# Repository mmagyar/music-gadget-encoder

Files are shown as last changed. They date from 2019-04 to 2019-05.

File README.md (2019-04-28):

# Music gadget base on STM32G070 MCU

# Modes of operation
 - Step sequencer
 - Midi controller
 
# Software
This project is built on a basic STM32Cube generated base, with using LL drivers.
TrueSTUDIO for STM32 is used for building and debugging.

# Hardware
The schematics and the pcb is designed with KiCad.
This is not a pcb that can be easily done at home, but most cheap chinease pcb manufaturers will be able to make them for you.
It uses 0805 SMD components, soldering this together is not for beginner.

# Picture of the prototype
In step sequencer mode:
in step sequencer mode

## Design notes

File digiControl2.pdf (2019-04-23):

## digiControl2 Project Configuration Report

# 1. Description

## 1.1. Project

Project Name | digiControl2
Board Name | custom
Generated with: | STM32CubeMX 5.0.0
Date | 04/14/2019

## 1.2. MCU

MCU Series | STM32G0
MCU Line | STM32G0x0 Value line
MCU name | STM32G070CBTx
MCU Package | LQFP48
MCU Pin number | 48

# 2. Pinout Configuration

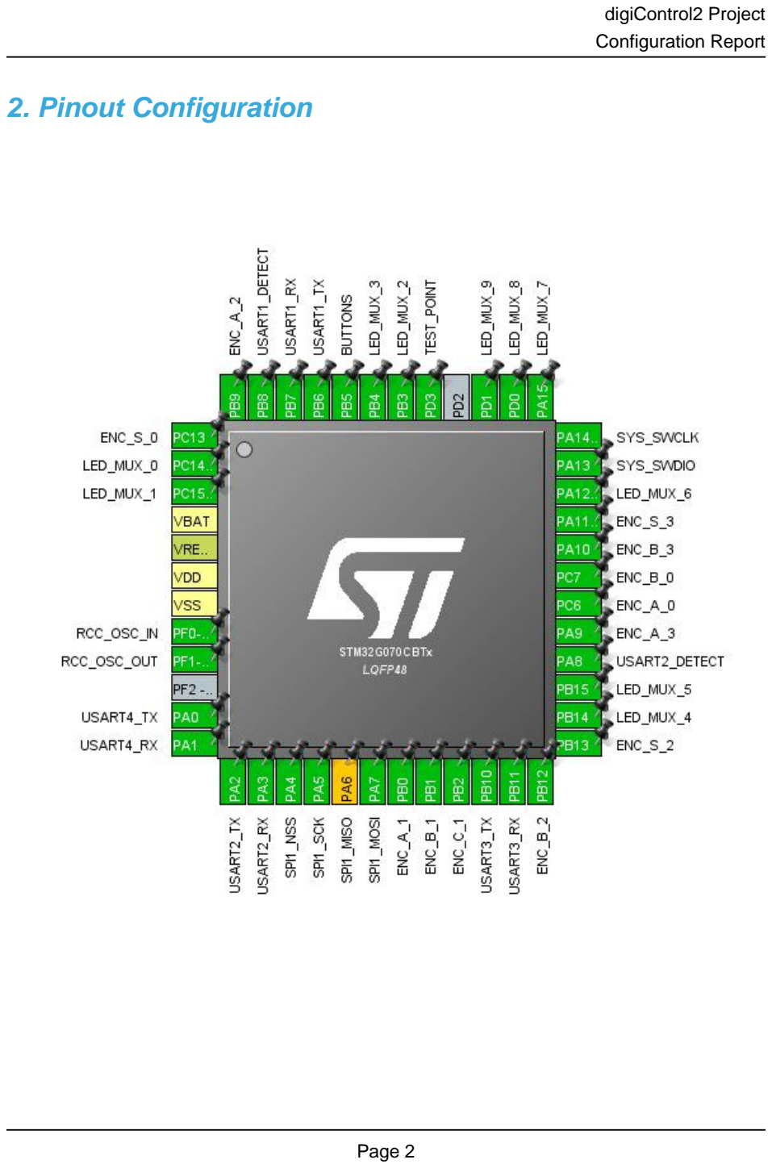
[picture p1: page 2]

# 3. Pins Configuration

Pin Number LQFP48 | Pin Name (function after reset) | Pin Type | Alternate Function(s) | Label
1 | PC13 * | I/O | GPIO_Input | ENC_S_0
2 | PC14-OSC32_IN (PC14) * | I/O | GPIO_Output | LED_MUX_0
3 | PC15-OSC32_OUT (PC15) * | I/O | GPIO_Output | LED_MUX_1
4 | VBAT | Power
5 | VREF+ | MonoIO
6 | VDD | Power
7 | VSS | Power
8 | PF0-OSC_IN (PF0) | I/O | RCC_OSC_IN
9 | PF1-OSC_OUT (PF1) | I/O | RCC_OSC_OUT
11 | PA0 | I/O | USART4_TX
12 | PA1 | I/O | USART4_RX
13 | PA2 | I/O | USART2_TX
14 | PA3 | I/O | USART2_RX
15 | PA4 | I/O | SPI1_NSS
16 | PA5 | I/O | SPI1_SCK
17 | PA6 ** | I/O | SPI1_MISO
18 | PA7 | I/O | SPI1_MOSI
19 | PB0 * | I/O | GPIO_Input | ENC_A_1
20 | PB1 * | I/O | GPIO_Input | ENC_B_1
21 | PB2 * | I/O | GPIO_Input | ENC_C_1
22 | PB10 | I/O | USART3_TX
23 | PB11 | I/O | USART3_RX
24 | PB12 * | I/O | GPIO_Input | ENC_B_2
25 | PB13 * | I/O | GPIO_Input | ENC_S_2
26 | PB14 * | I/O | GPIO_Output | LED_MUX_4
27 | PB15 * | I/O | GPIO_Output | LED_MUX_5
28 | PA8 * | I/O | GPIO_Input | USART2_DETECT
29 | PA9 * | I/O | GPIO_Input | ENC_A_3
30 | PC6 * | I/O | GPIO_Input | ENC_A_0
31 | PC7 * | I/O | GPIO_Input | ENC_B_0
32 | PA10 * | I/O | GPIO_Input | ENC_B_3
33 | PA11 [PA9] * | I/O | GPIO_Input | ENC_S_3
34 | PA12 [PA10] * | I/O | GPIO_Output | LED_MUX_6
35 | PA13 | I/O | SYS_SWDIO
36 | PA14-BOOT0 | I/O | SYS_SWCLK

Pin Number LQFP48 | Pin Name (function after reset) | Pin Type | Alternate Function(s) | Label
37 | PA15 * | I/O | GPIO_Output | LED_MUX_7
38 | PD0 * | I/O | GPIO_Output | LED_MUX_8
39 | PD1 * | I/O | GPIO_Output | LED_MUX_9
41 | PD3 * | I/O | GPIO_Output | TEST_POINT
42 | PB3 * | I/O | GPIO_Output | LED_MUX_2
43 | PB4 * | I/O | GPIO_Output | LED_MUX_3
44 | PB5 * | I/O | GPIO_Input | BUTTONS
45 | PB6 | I/O | USART1_TX
46 | PB7 | I/O | USART1_RX
47 | PB8 * | I/O | GPIO_Input | USART1_DETECT
48 | PB9 * | I/O | GPIO_Input | ENC_A_2

## * The pin is affected with an I/O function ** The pin is affected with a peripheral function but no peripheral mode is activated

# 4. Clock Tree Configuration

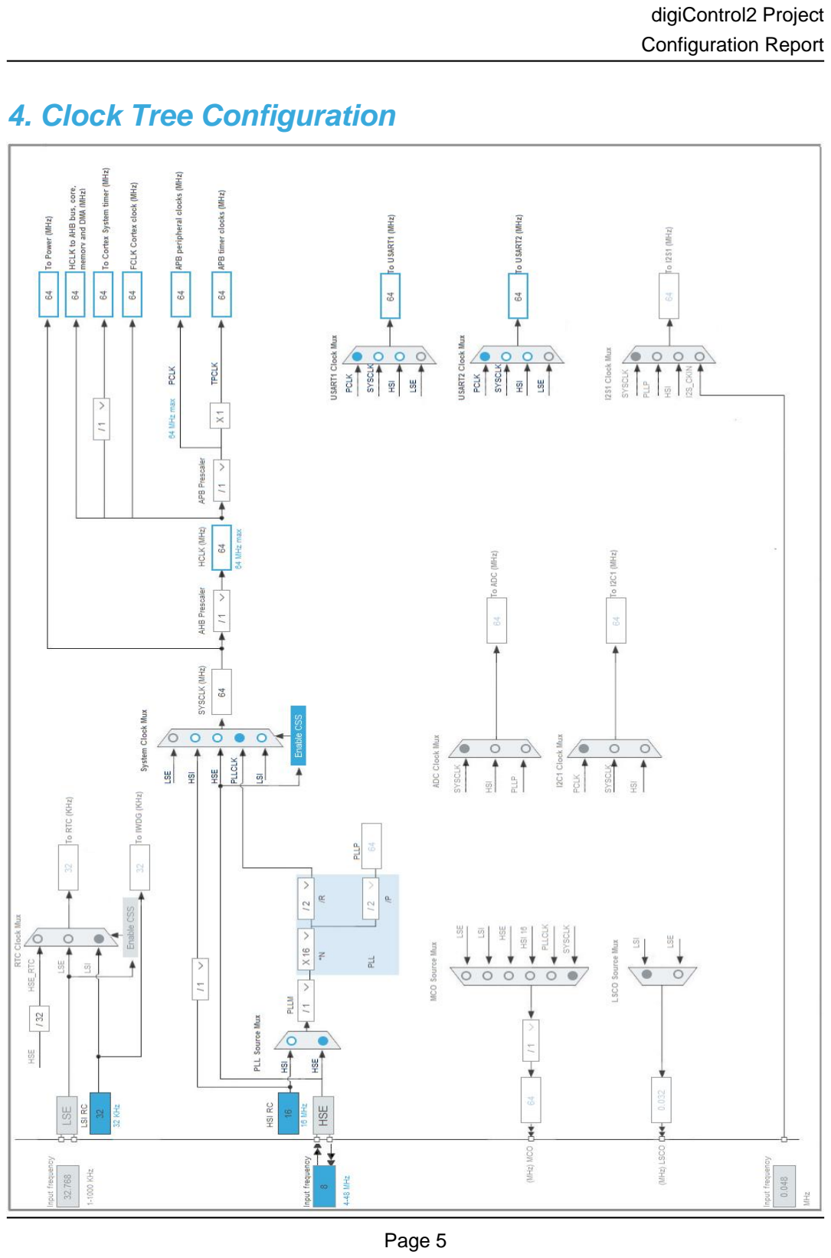
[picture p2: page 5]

# 5. Software Project

## 5.1. Project Settings

Name | Value
Project Name | digiControl2
Project Folder | C:\code\STM32_workspace_9.2\digiControl2\digiControl2
Toolchain / IDE | TrueSTUDIO
Firmware Package Name and Version | STM32Cube FW_G0 V1.0.0

## 5.2. Code Generation Settings

Name | Value
STM32Cube Firmware Library Package | Copy only the necessary library files
Generate peripheral initialization as a pair of '.c/.h' files | Yes
Backup previously generated files when re-generating | No
Delete previously generated files when not re-generated | Yes
Set all free pins as analog (to optimize the power consumption) | Yes

# 6. Power Consumption Calculator report

### 6.1. Microcontroller Selection

Series | STM32G0
Line | STM32G0x0 Value line
MCU | STM32G070CBTx
Datasheet | DS12766_Rev0

### 6.2. Parameter Selection

Temperature | 25
Vdd | null

# 7. IPs and Middleware Configuration

# 7.1. RCC

## High Speed Clock (HSE): Crystal/Ceramic Resonator 7.1.1. Parameter Settings:

### System Parameters:

VDD voltage (V) | 3.3
Instruction Cache | Enabled
Prefetch Buffer | Disabled
Data Cache | Enabled
Flash Latency(WS) | 2 WS (3 CPU cycle)

### RCC Parameters:

HSI Calibration Value | 64
HSE Startup Timout Value (ms) | 100
LSE Startup Timout Value (ms) | 5000

### Power Parameters:

Power Regulator Voltage Scale | Power Regulator Voltage Scale 1

### Peripherals Clock Configuration:

Generate the peripherals clock configuration | TRUE

# 7.2. SPI1

## Mode: Transmit Only Master Hardware NSS Signal: Hardware NSS Output Signal 7.2.1. Parameter Settings:

### Basic Parameters:

Frame Format | TI *
Data Size | 16 Bits *

### Clock Parameters:

Prescaler (for Baud Rate) | 4 *
Baud Rate | 16.0 MBits/s *

### Advanced Parameters:

CRC Calculation | Disabled
NSS Signal Type | Output Hardware

# 7.3. SYS

## mode: Debug Timebase Source: SysTick

# 7.4. USART1

## Mode: Asynchronous 7.4.1. Parameter Settings:

### Basic Parameters:

Baud Rate | 115200
Word Length | 9 Bits (including Parity) *
Parity | Even *
Stop Bits | 1

### Advanced Parameters:

Data Direction | Receive and Transmit
Over Sampling | 16 Samples
Single Sample | Disable
ClockPrescaler | clock /1
Fifo Mode | Disable
Txfifo Threshold | 1 eighth full configuration
Rxfifo Threshold | 1 eighth full configuration

### Advanced Features:

Auto Baudrate | Disable
TX Pin Active Level Inversion | Disable
RX Pin Active Level Inversion | Disable
Data Inversion | Disable
TX and RX Pins Swapping | Disable
Overrun | Enable
DMA on RX Error | Enable
MSB First | Disable

# 7.5. USART2

## Mode: Asynchronous 7.5.1. Parameter Settings:

### Basic Parameters:

Baud Rate | 115200
Word Length | 9 Bits (including Parity) *
Parity | Even *
Stop Bits | 1

### Advanced Parameters:

Data Direction | Receive and Transmit
Over Sampling | 16 Samples
Single Sample | Disable
ClockPrescaler | clock /1
Fifo Mode | Disable
Txfifo Threshold | 1 eighth full configuration
Rxfifo Threshold | 1 eighth full configuration

### Advanced Features:

Auto Baudrate | Disable
TX Pin Active Level Inversion | Disable
RX Pin Active Level Inversion | Disable
Data Inversion | Disable
TX and RX Pins Swapping | Disable
Overrun | Enable
DMA on RX Error | Enable
MSB First | Disable

# 7.6. USART3

## Mode: Asynchronous 7.6.1. Parameter Settings:

### Basic Parameters:

Baud Rate | 115200
Word Length | 9 Bits (including Parity) *
Parity | Even *
Stop Bits | 1

### Advanced Parameters:

Data Direction | Receive and Transmit
Over Sampling | 16 Samples
Single Sample | Disable
ClockPrescaler | clock /1
Fifo Mode | Disable
Txfifo Threshold | 1 eighth full configuration
Rxfifo Threshold | 1 eighth full configuration

### Advanced Features:

TX Pin Active Level Inversion | Disable
RX Pin Active Level Inversion | Disable
Data Inversion | Disable
TX and RX Pins Swapping | Disable
Overrun | Enable
DMA on RX Error | Enable
MSB First | Disable

# 7.7. USART4

## Mode: Asynchronous 7.7.1. Parameter Settings:

### Basic Parameters:

Baud Rate | 115200
Word Length | 9 Bits (including Parity) *
Parity | Even *
Stop Bits | 1

### Advanced Parameters:

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

### Advanced Features:

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

### * User modified value

# 8. System Configuration

# 8.1. GPIO configuration

IP | Pin | Signal | GPIO mode | GPIO pull/up pull down

## Max Speed

## User Label

RCC PF0-OSC_IN
(PF0)
RCC_OSC_IN | n/a | n/a | n/a

PF1-
OSC_OUT
(PF1)
RCC_OSC_OUT | n/a | n/a | n/a
SPI1 | PA4 | SPI1_NSS | Alternate Function Push Pull | No pull-up and no pull-down | High *
| PA5 | SPI1_SCK | Alternate Function Push Pull | No pull-up and no pull-down | High *
| PA7 | SPI1_MOSI | Alternate Function Push Pull | No pull-up and no pull-down | High *
SYS | PA13 | SYS_SWDIO | n/a | n/a | n/a
| PA14- BOOT0 | SYS_SWCLK | n/a | n/a | n/a
USART1 | PB6 | USART1_TX | Alternate Function Push Pull | Pull-up | Low
| PB7 | USART1_RX | Alternate Function Push Pull | Pull-up | Low
USART2 | PA2 | USART2_TX | Alternate Function Push Pull | Pull-up | Low
| PA3 | USART2_RX | Alternate Function Push Pull | Pull-up | Low
USART3 | PB10 | USART3_TX | Alternate Function Push Pull | Pull-up | Low
| PB11 | USART3_RX | Alternate Function Push Pull | Pull-up | Low
USART4 | PA0 | USART4_TX | Alternate Function Push Pull | Pull-up | Low
| PA1 | USART4_RX | Alternate Function Push Pull | Pull-up | Low
Single Mapped Signals | PA6 | SPI1_MISO | Alternate Function Push Pull | No pull-up and no pull-down | Low
GPIO | PC13 | GPIO_Input | Input mode | No pull-up and no pull-down | n/a | ENC_S_0
| PC14- OSC32_IN (PC14) | GPIO_Output | Output Push Pull | No pull-up and no pull-down | Low | LED_MUX_0

PC15-
OSC32_OU
T (PC15)
GPIO_Output | Output Push Pull | No pull-up and no pull-down | Low | LED_MUX_1
PB0 | GPIO_Input | Input mode | No pull-up and no pull-down | n/a | ENC_A_1
PB1 | GPIO_Input | Input mode | No pull-up and no pull-down | n/a | ENC_B_1
PB2 | GPIO_Input | Input mode | No pull-up and no pull-down | n/a | ENC_C_1
PB12 | GPIO_Input | Input mode | No pull-up and no pull-down | n/a | ENC_B_2
PB13 | GPIO_Input | Input mode | No pull-up and no pull-down | n/a | ENC_S_2
PB14 | GPIO_Output | Output Push Pull | No pull-up and no pull-down | Low | LED_MUX_4
PB15 | GPIO_Output | Output Push Pull | No pull-up and no pull-down | Low | LED_MUX_5
PA8 | GPIO_Input | Input mode | No pull-up and no pull-down | n/a | USART2_DETECT

IP | Pin | Signal | GPIO mode | GPIO pull/up pull down | Max Speed | User Label
| PA9 | GPIO_Input | Input mode | No pull-up and no pull-down | n/a | ENC_A_3
| PC6 | GPIO_Input | Input mode | No pull-up and no pull-down | n/a | ENC_A_0
| PC7 | GPIO_Input | Input mode | No pull-up and no pull-down | n/a | ENC_B_0
| PA10 | GPIO_Input | Input mode | No pull-up and no pull-down | n/a | ENC_B_3
| PA11 [PA9] | GPIO_Input | Input mode | No pull-up and no pull-down | n/a | ENC_S_3
| PA12 [PA10] | GPIO_Output | Output Push Pull | No pull-up and no pull-down | Low | LED_MUX_6
| PA15 | GPIO_Output | Output Push Pull | No pull-up and no pull-down | Low | LED_MUX_7
| PD0 | GPIO_Output | Output Push Pull | No pull-up and no pull-down | Low | LED_MUX_8
| PD1 | GPIO_Output | Output Push Pull | No pull-up and no pull-down | Low | LED_MUX_9
| PD3 | GPIO_Output | Output Push Pull | No pull-up and no pull-down | Low | TEST_POINT
| PB3 | GPIO_Output | Output Push Pull | No pull-up and no pull-down | Low | LED_MUX_2
| PB4 | GPIO_Output | Output Push Pull | No pull-up and no pull-down | Low | LED_MUX_3
| PB5 | GPIO_Input | Input mode | No pull-up and no pull-down | n/a | BUTTONS
| PB8 | GPIO_Input | Input mode | No pull-up and no pull-down | n/a | USART1_DETECT
| PB9 | GPIO_Input | Input mode | No pull-up and no pull-down | n/a | ENC_A_2

# 8.2. DMA configuration

DMA request | Stream | Direction | Priority
SPI1_TX | DMA1_Channel1 | Memory To Peripheral | Low

## SPI1_TX: DMA1_Channel1 DMA request Settings:

Mode: | Normal
Peripheral Increment: | Disable
Memory Increment: | Disable
Peripheral Data Width: | Half Word
Memory Data Width: | Half Word

# 8.3. NVIC configuration

Interrupt Table | Enable | Preenmption Priority | SubPriority
Non maskable interrupt | true | 0 | 0
Hard fault interrupt | true | 0 | 0
System service call via SWI instruction | true | 0 | 0
Pendable request for system service | true | 0 | 0
System tick timer | true | 0 | 0
RCC global interrupt | true | 0 | 0
DMA1 channel 1 interrupt | true | 0 | 0
DMA1 channel 4, channel 5, channel 6, channel 7 and DMAMUX1 interrupts | true | 0 | 0
SPI1 global interrupt | true | 0 | 0
Flash global interrupt | unused
USART1 global interrupt / USART1 wake-up interrupt through EXTI line 25 | unused
USART2 global interrupt / USART2 wake-up interrupt through EXTI line 26 | unused
USART3 and USART4 interrupts | unused

### * User modified value

# 9. Software Pack Report

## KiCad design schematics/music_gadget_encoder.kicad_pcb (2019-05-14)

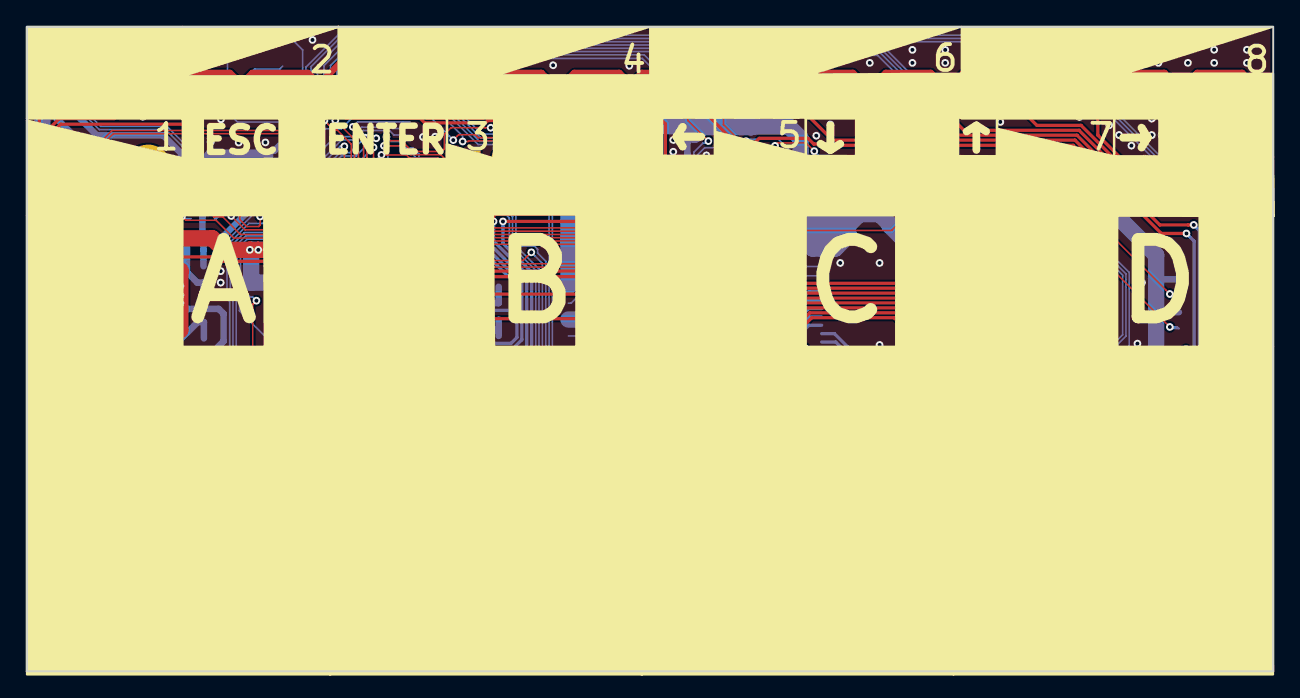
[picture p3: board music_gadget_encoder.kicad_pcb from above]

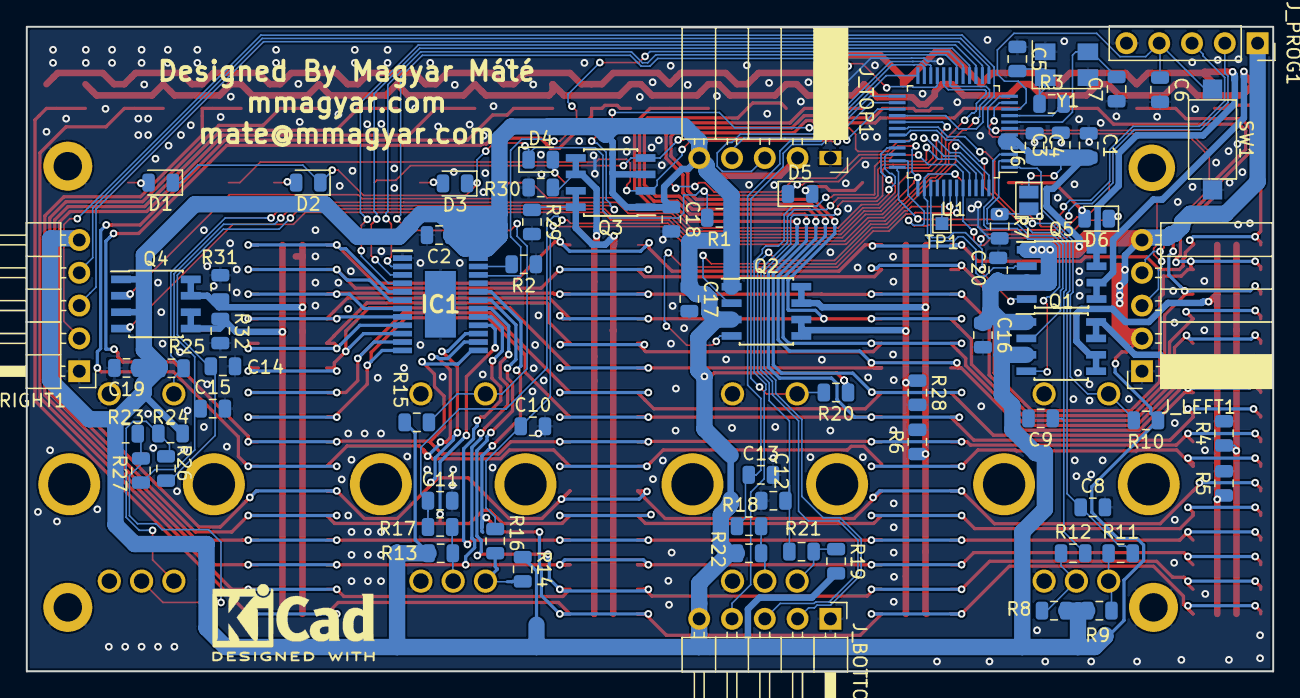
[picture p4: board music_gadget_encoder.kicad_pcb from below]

Board: 2 copper layers, 96.5 x 49.9 mm, 248 parts (74 on the bottom side), 87 nets.

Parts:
C1: 4.7u; C_0805_2012Metric
C2, C3, C4, C16, C17, C18, C19, C20: 100n; C_0805_2012Metric
C5, C7: 18pf; C_0805_2012Metric
C6: 100nf; C_0805_2012Metric
C8, C9, C10, C11, C12, C13, C14, C15: 10n; C_0805_2012Metric
D1, D2, D3, D4, D5, D6: DIODE; D_0805_2012Metric
D9, D10, D11, D12, D13, D14, D15, D16, D17, D18, D19, D20, D21, D22, D23, D24, D25, D26, D27, D28, D29, D30, D31, D32, D33, D34, D35, D36, D37, D38, D39, D40, D41, D42, D43, D44, D45, D46, D47, D48, D49, D50, D51, D52, D53, D54, D55, D56, D57, D58, D59, D60, D61, D62, D63, D64, D65, D66, D67, D68, D69, D70, D71, D72, D73, D74, D75, D76, D77, D78, D79, D80, D81, D82, D83, D84, D85, D86, D87, D88, D89, D90, D91, D92, D93, D94, D95, D96, D97, D98, D99, D100, D101, D102, D103, D104, D105, D106, D107, D108, D109, D110, D111, D112, D113, D114, D115, D116, D117, D118, D119, D120, D121, D122, D123, D124, D125, D126, D127, D128, D129, D130, D131, D132, D133, D134, D135, D136, D137, D138, D139, D140, D141, D142, D143, D144, D145, D146, D147, D148, D149, D150, D151, D152, D153, D154, D155, D156, D157, D158, D159, D160, D161, D162, D163, D164, D165, D166, D167, D168: LED; LED_0805_2012Metric_NO_SILKSCREEN
H1, H2, H3, H4: MountingHole_Pad; MountingHole_2.2mm_M2_DIN965_Pad
IC1: TLC5926IPWPR; SOP65P640X120-25N
J6: Conn_01x02_Male; SolderJumper-2_P1.3mm_Open_Pad1.0x1.5mm
J_BOTTOM1: Conn_01x05; PinHeader_1x05_P2.54mm_Horizontal
J_LEFT1: Conn_01x05; PinSocket_1x05_P2.54mm_Horizontal
J_PROG1: Conn_01x05; PinSocket_1x05_P2.54mm_Vertical
J_RIGHT1: Conn_01x05; PinHeader_1x05_P2.54mm_Horizontal
J_TOP1: Conn_01x05; PinSocket_1x05_P2.54mm_Horizontal
Q1, Q2, Q3, Q4, Q5: DMG9933USD-13; SOIC-8_3.9x4.9mm_P1.27mm
R1, R7: 10k; R_0805_2012Metric
R2: R; R_0805_2012Metric
R3: 390; R_0805_2012Metric
R4, R5, R6, R28, R29, R30, R31, R32: 1k; R_0805_2012Metric
R8, R9, R10, R11, R12, R13, R14, R15, R16, R17, R18, R19, R20, R21, R22, R23, R24, R25, R26, R27: 10K; R_0805_2012Metric
SW1, SW2, SW3, SW4, SW5, SW6, SW7: SW_Push; SW_SPST_CK_RS282G05A3
TP1: TestPoint; TestPoint_Pad_1.0x1.0mm
U1: STM32G070CBTx; LQFP-48_7x7mm_P0.5mm
U2, U3, U4, U5: PEC12R-4225F-S0024; ENCODER_PEC12R-4XXXF-SXXXX_1
Y1: Crystal_GND24; Crystal_SMD_5032-4Pin_5.0x3.2mm

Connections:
/BUTTONS: D1.1, D2.1, D3.1, D4.1, D5.1, D6.1, R1.2, U1.44
/ENC_A_0: C8.1, R11.2, U1.30
/ENC_A_1: C10.1, R16.2, U1.19
/ENC_A_2: C12.1, R21.2, U1.48
/ENC_A_3: C14.1, R26.2, U1.29
/ENC_B_0: C9.1, R12.2, U1.31
/ENC_B_1: C11.1, R17.2, U1.20
/ENC_B_2: C13.1, R22.2, U1.24
/ENC_B_3: C15.1, R27.2, U1.32
/ENC_S_0: R10.2, U1.1, U2.4
/ENC_S_1: R15.2, U1.21, U3.4
/ENC_S_2: R20.2, U1.25, U4.4
/ENC_S_3: R25.2, U1.33, U5.4
/LED_0: D9.1, D10.1, D41.1, D42.1, D73.1, D74.1, D105.1, D106.1, D137.1, D138.1, IC1.5
/LED_1: D11.1, D12.1, D43.1, D44.1, D75.1, D76.1, D107.1, D108.1, D139.1, D140.1, IC1.6
/LED_2: D13.1, D14.1, D45.1, D46.1, D77.1, D78.1, D109.1, D110.1, D141.1, D142.1, IC1.7
/LED_3: D15.1, D16.1, D47.1, D48.1, D79.1, D80.1, D111.1, D112.1, D143.1, D144.1, IC1.8
/LED_4: D17.1, D18.1, D49.1, D50.1, D81.1, D82.1, D113.1, D114.1, D145.1, D146.1, IC1.9
/LED_5: D19.1, D20.1, D51.1, D52.1, D83.1, D84.1, D115.1, D116.1, D147.1, D148.1, IC1.10
/LED_6: D21.1, D22.1, D53.1, D54.1, D85.1, D86.1, D117.1, D118.1, D149.1, D150.1, IC1.11
/LED_7: D23.1, D24.1, D55.1, D56.1, D87.1, D88.1, D119.1, D120.1, D151.1, D152.1, IC1.12
/LED_8: D25.1, D26.1, D57.1, D58.1, D89.1, D90.1, D121.1, D122.1, D153.1, D154.1, IC1.13
/LED_9: D27.1, D28.1, D59.1, D60.1, D91.1, D92.1, D123.1, D124.1, D155.1, D156.1, IC1.14
/LED_10: D29.1, D30.1, D61.1, D62.1, D93.1, D94.1, D125.1, D126.1, D157.1, D158.1, IC1.15
/LED_11: D31.1, D32.1, D63.1, D64.1, D95.1, D96.1, D127.1, D128.1, D159.1, D160.1, IC1.16
/LED_12: D33.1, D34.1, D65.1, D66.1, D97.1, D98.1, D129.1, D130.1, D161.1, D162.1, IC1.17
/LED_13: D35.1, D36.1, D67.1, D68.1, D99.1, D100.1, D131.1, D132.1, D163.1, D164.1, IC1.18
/LED_14: D37.1, D38.1, D69.1, D70.1, D101.1, D102.1, D133.1, D134.1, D165.1, D166.1, IC1.19
/LED_15: D39.1, D40.1, D71.1, D72.1, D103.1, D104.1, D135.1, D136.1, D167.1, D168.1, IC1.20
/LED_MUX_0: Q1.2, U1.2
/LED_MUX_1: Q1.4, U1.3
/LED_MUX_2: Q2.2, U1.42
/LED_MUX_3: Q2.4, U1.43
/LED_MUX_4: Q3.2, SW2.1, U1.26
/LED_MUX_5: Q3.4, SW3.1, U1.27
/LED_MUX_6: Q4.2, SW4.1, U1.34
/LED_MUX_7: Q4.4, SW5.1, U1.37
/LED_MUX_8: Q5.2, SW6.1, U1.38
/LED_MUX_9: Q5.4, SW7.1, U1.39
/MISO: IC1.22, U1.17
/MOSI: IC1.2, U1.18
/NSS: IC1.4, U1.15
/RESET: C6.1, J_PROG1.4, SW1.1, U1.10
/SCLK: IC1.3, U1.16
/SWCLK: J6.1, J_PROG1.3, R7.1, U1.36
/SWDIO: J_PROG1.2, U1.35
/USART1_DETECT: J_BOTTOM1.2, U1.47
/USART1_RX: J_BOTTOM1.3, U1.46
/USART1_TX: J_BOTTOM1.4, U1.45
/USART2_DETECT: J_RIGHT1.2, U1.28
/USART2_RX: J_RIGHT1.3, U1.14
/USART2_TX: J_RIGHT1.4, U1.13
/USART3_RX: J_TOP1.4, U1.23
/USART3_TX: J_TOP1.3, U1.22
/USART4_RX: J_LEFT1.4, U1.12
/USART4_TX: J_LEFT1.3, U1.11
GND: C1.1, C2.2, C3.2, C4.1, C5.1, C6.2, C7.1, C8.2, C9.2, C10.2, C11.2, C12.2, C13.2, C14.2, C15.2, C16.2, C17.2, C18.2, C19.2, C20.2, H1.1, H2.1, H3.1, H4.1, IC1.1, IC1.21, IC1.25, J_BOTTOM1.1, J_LEFT1.1, J_PROG1.5, J_RIGHT1.1, J_TOP1.1, R2.1, R4.2, R5.2, R6.2, R7.2, R28.2, R29.2, R30.2, R31.2, R32.2, SW1.2, U1.7, U2.2, U2.5, U3.2, U3.5, U4.2, U4.5, U5.2, U5.5, Y1.2, Y1.4
unnamed: C5.2, R3.1, Y1.1
unnamed: C7.2, U1.8, Y1.3
unnamed: D1.2, SW2.2
unnamed: D2.2, SW3.2
unnamed: D3.2, SW4.2
unnamed: D4.2, SW5.2
unnamed: D5.2, SW6.2
unnamed: D6.2, SW7.2
unnamed: D10.2, D12.2, D14.2, D16.2, D18.2, D20.2, D22.2, D24.2, D26.2, D28.2, D30.2, D32.2, D34.2, D36.2, D38.2, D40.2, Q1.7, Q1.8, R4.1
unnamed: D9.2, D11.2, D13.2, D15.2, D17.2, D19.2, D21.2, D23.2, D25.2, D27.2, D29.2, D31.2, D33.2, D35.2, D37.2, D39.2, Q1.5, Q1.6, R5.1
unnamed: D41.2, D43.2, D45.2, D47.2, D49.2, D51.2, D53.2, D55.2, D57.2, D59.2, D61.2, D63.2, D65.2, D67.2, D69.2, D71.2, Q2.5, Q2.6, R28.1
unnamed: D42.2, D44.2, D46.2, D48.2, D50.2, D52.2, D54.2, D56.2, D58.2, D60.2, D62.2, D64.2, D66.2, D68.2, D70.2, D72.2, Q2.7, Q2.8, R6.1
unnamed: D74.2, D76.2, D78.2, D80.2, D82.2, D84.2, D86.2, D88.2, D90.2, D92.2, D94.2, D96.2, D98.2, D100.2, D102.2, D104.2, Q3.7, Q3.8, R29.1
unnamed: D73.2, D75.2, D77.2, D79.2, D81.2, D83.2, D85.2, D87.2, D89.2, D91.2, D93.2, D95.2, D97.2, D99.2, D101.2, D103.2, Q3.5, Q3.6, R30.1
unnamed: D105.2, D107.2, D109.2, D111.2, D113.2, D115.2, D117.2, D119.2, D121.2, D123.2, D125.2, D127.2, D129.2, D131.2, D133.2, D135.2, Q4.5, Q4.6, R32.1
unnamed: D106.2, D108.2, D110.2, D112.2, D114.2, D116.2, D118.2, D120.2, D122.2, D124.2, D126.2, D128.2, D130.2, D132.2, D134.2, D136.2, Q4.7, Q4.8, R31.1
unnamed: D137.2, D139.2, D141.2, D143.2, D145.2, D147.2, D149.2, D151.2, D153.2, D155.2, D157.2, D159.2, D161.2, D163.2, D165.2, D167.2, Q5.5, Q5.6
unnamed: D138.2, D140.2, D142.2, D144.2, D146.2, D148.2, D150.2, D152.2, D154.2, D156.2, D158.2, D160.2, D162.2, D164.2, D166.2, D168.2, Q5.7, Q5.8
unnamed: IC1.23, R2.2
unnamed: R3.2, U1.9
unnamed: R9.2, R11.1, U2.1
unnamed: R8.2, R12.1, U2.3
unnamed: R13.2, R17.1, U3.3
unnamed: R14.2, R16.1, U3.1
unnamed: R18.2, R22.1, U4.3
unnamed: R19.2, R21.1, U4.1
unnamed: R23.2, R27.1, U5.3
unnamed: R24.2, R26.1, U5.1
unnamed: TP1.1, U1.41
VCC: C1.2, C2.1, C3.1, C4.2, C16.1, C17.1, C18.1, C19.1, C20.1, IC1.24, J6.2, J_BOTTOM1.5, J_LEFT1.2, J_LEFT1.5, J_PROG1.1, J_RIGHT1.5, J_TOP1.2, J_TOP1.5, Q1.1, Q1.3, Q2.1, Q2.3, Q3.1, Q3.3, Q4.1, Q4.3, Q5.1, Q5.3, R1.1, R8.1, R9.1, R10.1, R13.1, R14.1, R15.1, R18.1, R19.1, R20.1, R23.1, R24.1, R25.1, U1.4, U1.5, U1.6

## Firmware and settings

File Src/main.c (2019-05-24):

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

/* Includes ------------------------------------------------------------------*/
#include "main.h"
#include "crc.h"
#include "spi.h"
#include "tim.h"
#include "usart.h"
#include "gpio.h"

/* USER CODE BEGIN Includes */
#include "mainthread.h"
#include "lib/printf.h"
/* USER CODE END Includes */


void SystemClock_Config(void);
static void MX_NVIC_Init(void);
/**
 * @brief  The application entry point.
 * @retval int
 */
int main(void)
{
    /* MCU Configuration--------------------------------------------------------*/

    /* Reset of all peripherals, Initializes the Flash interface and the Systick. */

    LL_APB2_GRP1_EnableClock(LL_APB2_GRP1_PERIPH_SYSCFG);
    LL_APB1_GRP1_EnableClock(LL_APB1_GRP1_PERIPH_PWR);

    /* System interrupt init*/

    /* Peripheral interrupt init*/

    /* Configure the system clock */
    SystemClock_Config();

    /* Initialize all configured peripherals */
    MX_GPIO_Init();
    MX_SPI1_Init();
    MX_USART1_UART_Init();
    MX_USART2_UART_Init();
    MX_USART3_UART_Init();
    MX_USART4_UART_Init();
    MX_TIM3_Init();
    MX_TIM6_Init();
    MX_TIM7_Init();
    MX_TIM14_Init();
    MX_CRC_Init();

    /* Initialize interrupts */
    MX_NVIC_Init();
    /* Infinite loop */
    /* USER CODE BEGIN WHILE */

//    /* Start channel 3 in Output compare mode */
//    if (HAL_TIM_OC_Start_IT(&htim3, TIM_CHANNEL_1) != HAL_OK) {
//        /* Starting Error */
//        Error_Handler();
//    }
    LL_TIM_EnableCounter(TIM6);
    LL_TIM_EnableIT_UPDATE(TIM6);

    LL_TIM_EnableCounter(TIM7);
    LL_TIM_EnableIT_UPDATE(TIM7);

    LL_TIM_EnableCounter(TIM3);
    LL_TIM_EnableIT_UPDATE(TIM3);

    LL_TIM_EnableCounter(TIM14);
    LL_TIM_EnableIT_UPDATE(TIM14);

    LL_SPI_Enable(SPI1);
    LL_SPI_EnableIT_RXNE(SPI1);


    while ((!(LL_USART_IsActiveFlag_TEACK(USART4))) || (!(LL_USART_IsActiveFlag_REACK(USART4))));
    LL_USART_EnableIT_RXNE(USART4);
    LL_USART_EnableIT_ERROR(USART4);

    while ((!(LL_USART_IsActiveFlag_TEACK(USART3))) || (!(LL_USART_IsActiveFlag_REACK(USART3))));
    LL_USART_EnableIT_RXNE(USART3);
    LL_USART_EnableIT_ERROR(USART3);

    while ((!(LL_USART_IsActiveFlag_TEACK(USART2))) || (!(LL_USART_IsActiveFlag_REACK(USART2))));
    LL_USART_EnableIT_RXNE(USART2);
    LL_USART_EnableIT_ERROR(USART2);

    while ((!(LL_USART_IsActiveFlag_TEACK(USART1))) || (!(LL_USART_IsActiveFlag_REACK(USART1))));
    LL_USART_EnableIT_RXNE(USART1);
    LL_USART_EnableIT_ERROR(USART1);
//    LL_USART_TransmitData8(USART4, 'x');


    main_thread();

    /* USER CODE END WHILE */

}

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


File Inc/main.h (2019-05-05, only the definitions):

#define ENC_S_0_Pin LL_GPIO_PIN_13
#define ENC_S_0_GPIO_Port GPIOC
#define LED_MUX_0_Pin LL_GPIO_PIN_14
#define LED_MUX_0_GPIO_Port GPIOC
#define LED_MUX_1_Pin LL_GPIO_PIN_15
#define LED_MUX_1_GPIO_Port GPIOC
#define ENC_A_2_Pin LL_GPIO_PIN_0
#define ENC_A_2_GPIO_Port GPIOB
#define ENC_B_2_Pin LL_GPIO_PIN_1
#define ENC_B_2_GPIO_Port GPIOB
#define ENC_S_2_Pin LL_GPIO_PIN_2
#define ENC_S_2_GPIO_Port GPIOB
#define ENC_B_1_Pin LL_GPIO_PIN_12
#define ENC_B_1_GPIO_Port GPIOB
#define ENC_S_1_Pin LL_GPIO_PIN_13
#define ENC_S_1_GPIO_Port GPIOB
#define LED_MUX_4_Pin LL_GPIO_PIN_14
#define LED_MUX_4_GPIO_Port GPIOB
#define LED_MUX_5_Pin LL_GPIO_PIN_15
#define LED_MUX_5_GPIO_Port GPIOB
#define USART2_DETECT_Pin LL_GPIO_PIN_8
#define USART2_DETECT_GPIO_Port GPIOA
#define ENC_A_3_Pin LL_GPIO_PIN_9
#define ENC_A_3_GPIO_Port GPIOA
#define ENC_A_0_Pin LL_GPIO_PIN_6
#define ENC_A_0_GPIO_Port GPIOC
#define ENC_B_0_Pin LL_GPIO_PIN_7
#define ENC_B_0_GPIO_Port GPIOC
#define ENC_B_3_Pin LL_GPIO_PIN_10
#define ENC_B_3_GPIO_Port GPIOA
#define ENC_S_3_Pin LL_GPIO_PIN_11
#define ENC_S_3_GPIO_Port GPIOA
#define LED_MUX_6_Pin LL_GPIO_PIN_12
#define LED_MUX_6_GPIO_Port GPIOA
#define LED_MUX_7_Pin LL_GPIO_PIN_15
#define LED_MUX_7_GPIO_Port GPIOA
#define LED_MUX_8_Pin LL_GPIO_PIN_0
#define LED_MUX_8_GPIO_Port GPIOD
#define LED_MUX_9_Pin LL_GPIO_PIN_1
#define LED_MUX_9_GPIO_Port GPIOD
#define TEST_POINT_Pin LL_GPIO_PIN_3
#define TEST_POINT_GPIO_Port GPIOD
#define LED_MUX_2_Pin LL_GPIO_PIN_3
#define LED_MUX_2_GPIO_Port GPIOB
#define LED_MUX_3_Pin LL_GPIO_PIN_4
#define LED_MUX_3_GPIO_Port GPIOB
#define BUTTONS_Pin LL_GPIO_PIN_5
#define BUTTONS_GPIO_Port GPIOB
#define USART1_DETECT_Pin LL_GPIO_PIN_8
#define USART1_DETECT_GPIO_Port GPIOB
#define ENC_A_1_Pin LL_GPIO_PIN_9
#define ENC_A_1_GPIO_Port GPIOB
#define NVIC_PRIORITYGROUP_0         ((uint32_t)0x00000007) /*!< 0 bit  for pre-emption priority,
#define NVIC_PRIORITYGROUP_1         ((uint32_t)0x00000006) /*!< 1 bit  for pre-emption priority,
#define NVIC_PRIORITYGROUP_2         ((uint32_t)0x00000005) /*!< 2 bits for pre-emption priority,
#define NVIC_PRIORITYGROUP_3         ((uint32_t)0x00000004) /*!< 3 bits for pre-emption priority,
#define NVIC_PRIORITYGROUP_4         ((uint32_t)0x00000003) /*!< 4 bits for pre-emption priority,

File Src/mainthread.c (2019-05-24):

#include "mainthread.h"
#include "stm32g070xx.h"
#include "tim.h"
#include "util/error_log_code_text.h"
#include  <sys/unistd.h> // STDOUT_FILENO, STDERR_FILENO
#include "lib/printf.h"
#include "seq/seq.h"
#include "seq/control.h"
#include "system/inputs.h"
#include "system/led_update.h"
#include "system/mux.h"
#include "util/midi/midi.h"
#include "util/dataframe.h"
#include "system/intercom.h"
#include "system/uart.h"

Task tasks[max_task_count] = { 0 };
u32 ms_counter = 0;
u32 ms_last = 0;
const u8 TASK_INDEX_LED_UPDATE = 0;
const u8 TASK_INDEX_SEQ_UPDATE = 1;
const u8 TASK_INDEX_CONTROL_UPDATE = 2;
const u8 TASK_INDEX_COMM = 3;
const u8 TASK_ERROR_PRINT = 4;

u32 received_frames_count = 0;

void calculate_task_time(Task * task);

Icom_send icom_buffer[4] = { 0 };
Frame_Receive_buffer frame_buffer[4] = { 0 };

volatile int azz = 0;
void test_receive_control_change(Mcu_uid * origin, Control_change ch) {
    azz++;
 //   icom_send_control_change(&ch);
}
void test_receive_button_press(Mcu_uid * origin, Button_press bp) {
    azz++;
}
void test_receive_led_update(Mcu_uid * origin, Led_update lu) {
    azz++;
}

void test_receive_broadcast_response(Mcu_uid * origin, Broadcast_response br) {
    azz++;
}
void read_uart_rx_buffer() {
    Circular_buffer * cb[4] = {
            &uart_1_rx_buffer,
            &uart_2_rx_buffer,
            &uart_3_rx_buffer,
            &uart_4_rx_buffer };

    loop(x, 4)
    {
        Buffer_read_result brr = { 0 };

        get_from_buffer(cb[x], &brr);

        if (brr.readSuccess) {
            bool frame_end = receive_byte(brr.data, &frame_buffer[x]);

            if (frame_end) {
                received_frames_count++;
                icom_read_message(frame_buffer[x].buffer, frame_buffer[x].message_size,
                        &icom_buffer[x], x + 1);
            }
        }
    }

}

void error_print() {
    if (error_count) {
        printf("\r\nTotal number of errors occured: %d\r\n", error_count);
        loop(ec, ERROR_LOG_SIZE)
        {
            Error * e = &error_log[ec];
            if (e->error_code) {
                printf("ERR 0x%02X - %c (%d) : %s\r\n", e->error_code, e->identifier, e->identifier,
                        error_code_text[(u8) e->error_code]);

                e->error_code = 0;
                e->identifier = 0;
            }

        }
        error_count = 0;
    }
}

volatile int abcd = 0;
void test() {
    return;
    loop(x,8)
    {
        Control_change ch = { x, x * 2 };
        icom_send_control_change(&ch);
        volatile int i = 0;
        while (i < 100) {
            i++;
        }

    }

    //  Control_change ch = { 1, abcd++ };
    //  icom_send_control_change(&ch);
}
void crc_feed_stm32(Crc_state state, u8 byte) {
    LL_CRC_FeedData8(CRC, byte);
}

Crc_state crc_init_stm32() {
    LL_CRC_ResetCRCCalculationUnit(CRC);
    return 0;
}

u32 crc_get_stm32(Crc_state state) {
    u32 data = LL_CRC_ReadData32(CRC);
    LL_CRC_ResetCRCCalculationUnit(CRC);
    /* We need to invert it to get a standard CRC32*/
    return (~data);
}
void init_tasks() {

    /**
     * Stack guard
     */
    u32 memory_end = 0x20009000;
    u32 stack_beginning = memory_end - 0x400;
    u32 deadbeef_addr = stack_beginning - 0x8;
    u32 * var = (u32 *) deadbeef_addr;
    *var = 0xEFBEADDE;
    icom_receive_control_change = test_receive_control_change;
    icom_receive_button_press = &test_receive_button_press;
    icom_receive_led_update = &test_receive_led_update;

    //midi_bytes_ready_to_send = send_buffer_uart_3;

    tasks[TASK_INDEX_LED_UPDATE].task = &update_display;

    tasks[TASK_INDEX_SEQ_UPDATE].task = &update_seq;
    tasks[TASK_INDEX_SEQ_UPDATE].repeat_ms = 0;

    /** Configurte this task to run every 16ms (~60hz) **/
    tasks[TASK_INDEX_CONTROL_UPDATE].task = &process_control;
    tasks[TASK_INDEX_CONTROL_UPDATE].repeat_ms = 16;

    /** Configure this task to run on every loop **/
    tasks[TASK_INDEX_COMM].dont_reset_needs_run = true;
    tasks[TASK_INDEX_COMM].needs_run = true;
    tasks[TASK_INDEX_COMM].task = read_uart_rx_buffer;

    tasks[TASK_ERROR_PRINT].task = error_print;
    tasks[TASK_ERROR_PRINT].repeat_ms = 100;
    tasks[7].repeat_ms = 1000;
    tasks[7].task = &test;

    crc_feed = &crc_feed_stm32;
    crc_get = &crc_get_stm32;
    crc_init = &crc_init_stm32;
}
char chr = 0;
u64 aha = 0;
void main_thread() {

    init_tasks();
    //printf("\r\nSTARTING UP %d\r\n", 4);

    icom_send_address_request();
    loop(x,5)
    {
        Control_change ch = { x, x * 2 };
        //      icom_send_control_change(&ch);
    }

    while (1) {

        if (ms_counter != ms_last) {
            loop(task_i, max_task_count)
            {
                u32 repeat = tasks[task_i].repeat_ms;
                if (repeat) {
                    if (ms_counter > repeat + tasks[task_i].last_run_ms) {
                        tasks[task_i].needs_run = true;
                    }
                }
            }

            ms_last = ms_counter;
        }
        loop(task_i, max_task_count)
        {
            Task * task = &tasks[task_i];
            if (task->needs_run && task->task != NULL) {
                task->start_clk = TIM3->CNT;
                task->start_ms = ms_counter;
                task->task();

                if (!task->dont_reset_needs_run) {
                    task->needs_run = false;
                }
                task->last_run_ms = ms_counter;
                task->end_clk = TIM3->CNT;
                task->end_ms = ms_counter;

                calculate_task_time(task);

            }

        }

        if (button_pressed[0]) {
            //  button_pressed[0]--;
            // printf("HELLO, loop time of led update: %d\r\n", (int) tasks[0].avg_time);
        }

    }

}

void calculate_task_time(Task * task) {
    u32 ms_diff = task->end_ms - task->start_ms;
    if (ms_diff) {
        //Add the passed milliseconds
        task->last_time = (ms_diff - 1) * (u64) 1000;
        //Add the remaining part from the start part
        task->last_time += (1000 - task->start_clk);
        //Add the ticks passed since the last ms
        task->last_time += task->end_clk;
    } else {
        task->last_time = task->end_clk - task->start_clk;
    }

    u64 last_avg = task->avg_time;
    u8 avgs = 8;
    u64 new_avg = 0;
    loop(avg_i, (avgs - 1U))
    {
        new_avg += last_avg;
    }
    task->avg_time = (new_avg + task->last_time) / avgs;
}

/**
 * Elapsed_time_counter
 */
void TIM3_IRQHandler(void)
{
    ms_counter++;
    seq.current_ms = ms_counter;
    LL_TIM_ClearFlag_UPDATE(TIM3);
}
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

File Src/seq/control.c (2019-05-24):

#include "control.h"
#include "../system/inputs.h"
#include "../util/midi/midi.h"
#include "../util/midi/midi_enums.h"
#include "../system/led_update.h"
#include "../util/counter.h"
#include "../system/intercom.h"
#define MIDI_ON false
Control_encoder_config encoder_config[8] = {
        { CT_INCREMENT, 0, 16 /* maybe 80 */, 1, 65, { CT_TOGGLE, 0, 32, 0 }, 0 },
        { CT_INCREMENT, 0, 17 /* maybe 81 */, 1, 65, { CT_TOGGLE, 0, 33, 0 }, 0 },
        { CT_INCREMENT, 0, 18 /* maybe 82 */, 1, 65, { CT_TOGGLE, 0, 34, 0 }, 0 },
        { CT_INCREMENT, 0, 19 /* maybe 83 */, 1, 65, { CT_TOGGLE, 0, 35, 0 }, 0 },
        { CT_INCREMENT, 0, 20, 1, 65, { CT_TOGGLE, 0, 36, 0 }, 0 },
        { CT_INCREMENT, 0, 21, 1, 65, { CT_TOGGLE, 0, 37, 0 }, 0 },
        { CT_INCREMENT, 0, 22, 1, 65, { CT_TOGGLE, 0, 38, 0 }, 0 },
        { CT_INCREMENT, 0, 23, 1, 65, { CT_TOGGLE, 0, 39, 0 }, 0 },
};

Control_button_config buttons[6] = {
        { CT_PRESS, 0, 93, 0 }, /* STOP */
        { CT_PRESS, 0, 94, 0 }, /* PLAY */
        { CT_PRESS, 0, 8, 0 }, /* SOLO 1 */
        { CT_PRESS, 0, 9, 0 }, /* SOLO 2 */
        { CT_PRESS, 0, 10, 0 }, /* SOLO 3 */
        { CT_PRESS, 0, 11, 0 }, /* SOLO 4 */
};

Counter encs[4] = {
        { 31, OFB_SATURATE, 0 }, { 31, OFB_SATURATE, 0 },
        { 31, OFB_SATURATE, 0 }, { 31, OFB_SATURATE, 0 } };
bool btns[6] = { 0 };

void led_update() {
    loop(x,4)
    {
        u8 data = encs[x].data * 8;
        led_calculate_bar_16(data ? data + 6 : 0, display.encoders[x].red_precise);
    }

    loop(x,4)
    {
        led_calculate_bar_16(buttons[x].button_state * 2, display.encoders[x].green_precise);
    }

    loop(x,2)
    {
        led_calculate_bar_16(buttons[x + 4].button_state * 2, display.top_bar_precise);
    }
}

void process_control() {
    //TODO LED control
    //TODO midi input
    loop(i,6)
    {
        if (button_pressed[i]) {
            button_pressed[i]--;
            Control_button_config * btn = &buttons[i];
            if (btn->type == CT_TOGGLE) {
                btn->button_state = btn->button_state ? 0 : 127;
                if (MIDI_ON) send_note_on((Midi_channel) btn->channel, btn->button_note,
                        btn->button_state);

            } else {
                btn->button_state = btn->button_state ? 0 : 127;
                if (MIDI_ON) send_note_on((Midi_channel) btn->channel, btn->button_note, 127);
            }
            Button_press bp = { i };
            icom_send_button_press(&bp);
        }
    }

    loop(x,4)
    {

        Control_encoder_config * encoder = &encoder_config[x];

        s16 * step = &encoders[x].encoder_step;
        bool changed = *step ? true : false;
        while(encoders[x].button_presses){
            encoders[x].button_presses--;
            icom_send_broadcast_request();
        }
        if (encoder->type == CT_INCREMENT) {
            while (*step != 0) {
                if (*step > 0) {
                    *step -= 1;
                    if (MIDI_ON) send_cc((Midi_channel) encoder->channel,
                            (Midi_cc_number) encoder->cc,
                            encoder->increment_value);
                    counter_inc(&encs[x]);

                } else {
                    *step += 1;
                    counter_dec(&encs[x]);
                    if (MIDI_ON) send_cc((Midi_channel) encoder->channel,
                            (Midi_cc_number) encoder->cc,
                            encoder->decrement_value);
                }
            }

        } else if (encoder->type == CT_VALUE) {
            while (*step != 0) {
                if (*step > 0) {
                    *step -= 1;
                    if (encoder->data <= 127) encoder->data++;
                } else {
                    *step += 1;
                    if (encoder->data) encoder->data--;
                }

            }
            counter_set(encoder->data, &encs[x]);
            if (MIDI_ON) send_cc((Midi_channel) encoder->channel, (Midi_cc_number) encoder->cc,
                    encoder->data);
        }

        if (changed) {
            Control_change ch = { x, encs[x].data };
            icom_send_control_change(&ch);
        }
    }

    led_update();
}

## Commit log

2019-04-27 add schematics
    [LED_ROW.sch, encoder_unit.sch, music_gadget_encoder.kicad_pcb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]
2019-05-07 update stm32 cube project with crc settings
2019-05-14 update pcb
    [LED_ROW.sch, encoder_unit.sch, music_gadget_encoder.kicad_pcb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]
2019-05-18 putchar for printing don't need a buffer
2019-05-18 update error printing
2019-05-18 update to stm32cubeide from truestudio
2019-05-24 add address broadcasting for device discovery

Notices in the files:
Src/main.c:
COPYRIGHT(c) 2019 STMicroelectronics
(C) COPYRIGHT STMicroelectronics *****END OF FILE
